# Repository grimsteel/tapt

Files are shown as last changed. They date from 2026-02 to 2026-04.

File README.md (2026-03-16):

# tapt

> just a button

`tapt` is a BLE-powered IoT button. It uses an nRF52810 and can be powered for long periods of time on a single CR2032 battery.

It can be connected to Home Assistant and hooked up to automations from there.

## Usage

> Note: do NOT connect the battery when the board is powered on the debug header.

### Assembly

1. The 5 pin debug header must be soldered on for flashing
2. The battery holder can be soldered onto the back 
3. The WS2812B and the UART are optional. Both of these will cause more battery drain.
4. The PCB can be screwed into the base of the case. The button cap locks into the case.

### Flashing

> Note: An nRF-SDK environment is required. This is a *freestanding project*

1. Customize the device ID and board name if needed in `prj.conf`
1. Build the firmware:
   ```sh
   west build -b tapt -- -DBOARD_ROOT=.
   ```
1. Flash the nRF over SWD, using the SWD header on the board. The pins are labeled on the bottom.

   Firmware is included in the `./firmware` directory.
3. Profit. The button should be autodiscovered in Home Assistant, where it will expose a button entity.

## Purpose

I made this because I wanted a large button for controlling random automations.

I also wanted to learn more about RF PCB design, and the nRF chip was a great place to start.

## Schematic + PCB

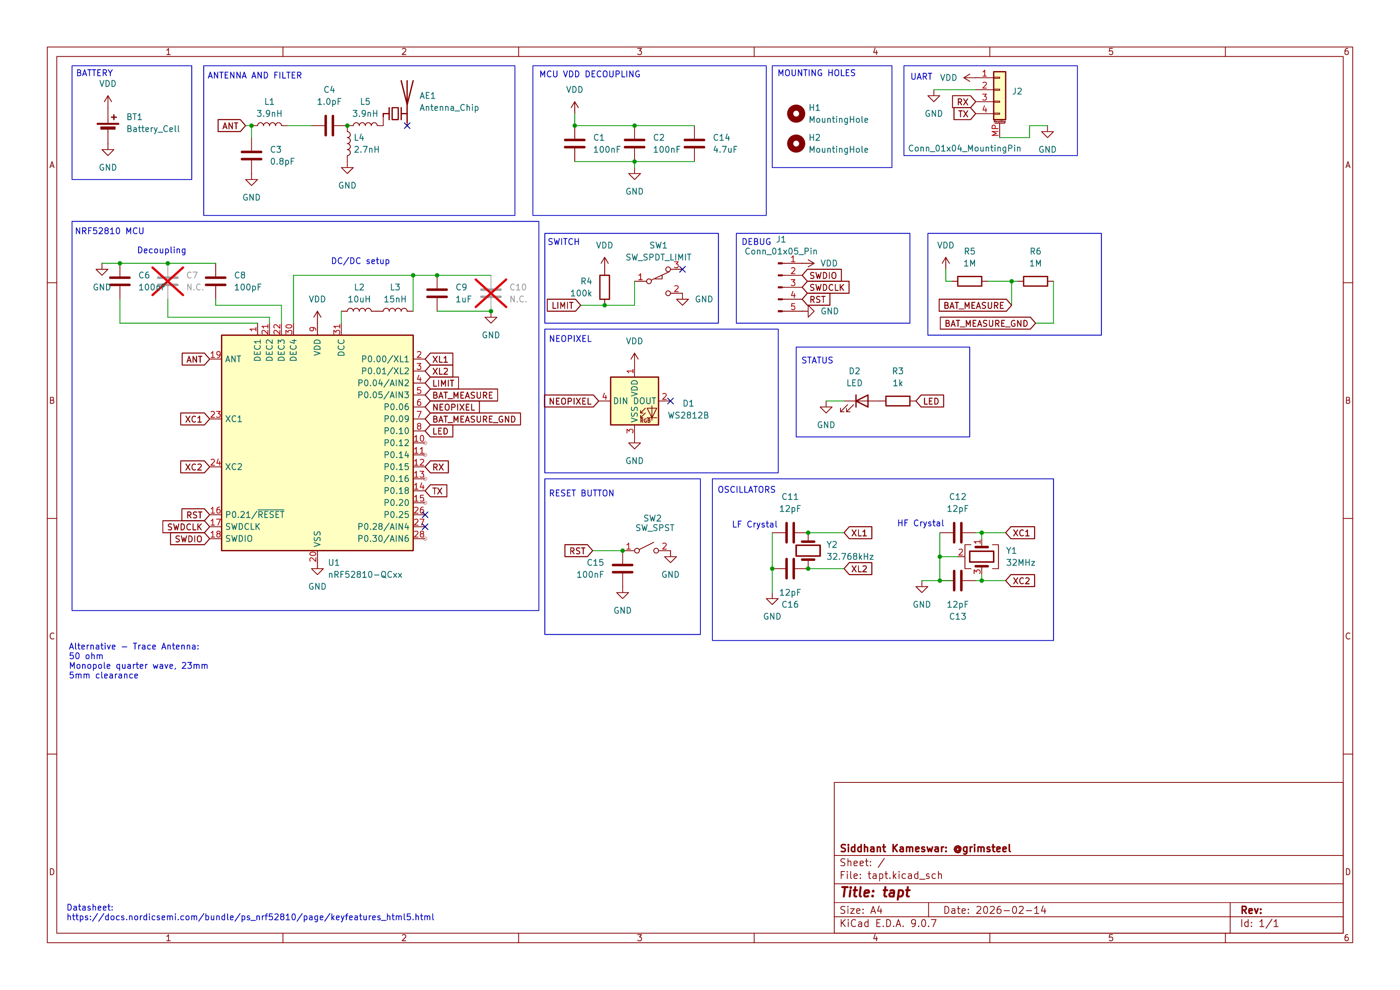
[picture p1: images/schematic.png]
schematic


| F.Cu | In1.Cu | In2.Cu | B.Cu |
|---|---|---|---|
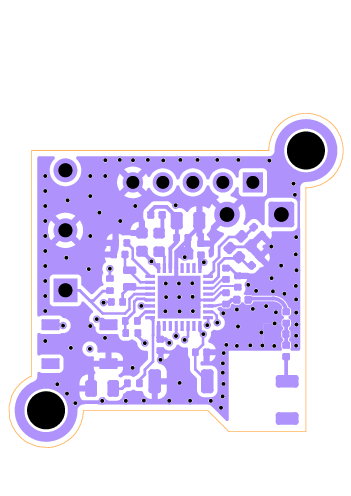
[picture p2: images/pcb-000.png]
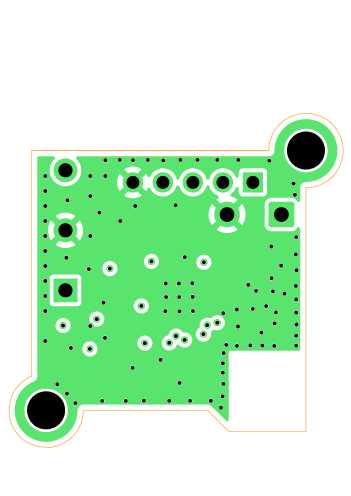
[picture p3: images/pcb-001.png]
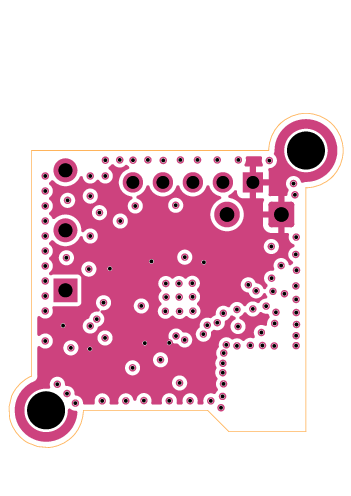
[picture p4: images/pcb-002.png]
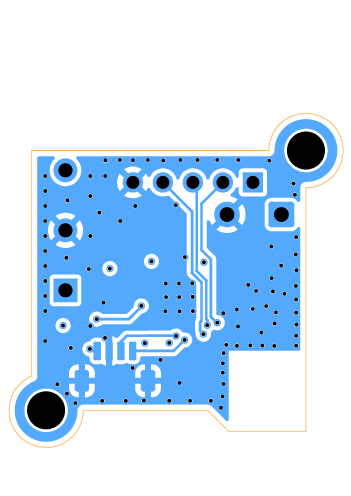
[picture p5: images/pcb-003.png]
|  |  |  |  |
| | | | |

## Case

Apart from the PCB, tapt just has two components: the base and the button. 

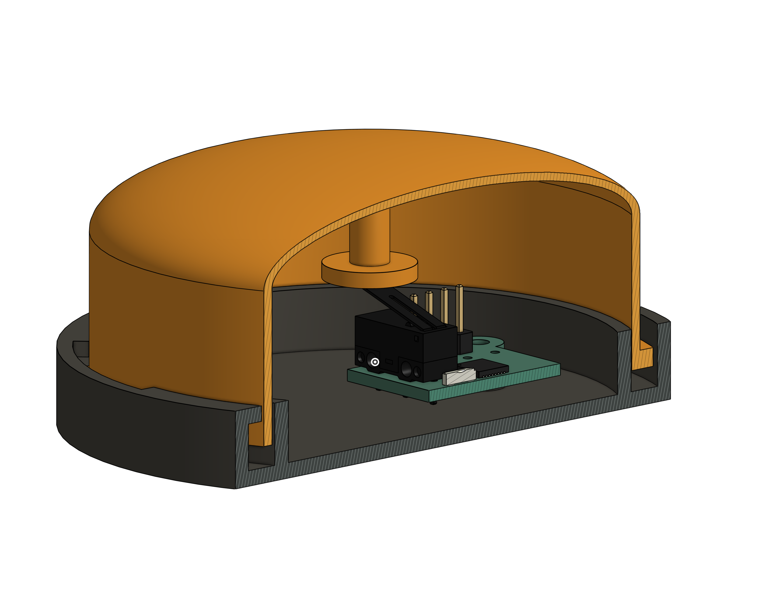
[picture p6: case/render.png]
cad render

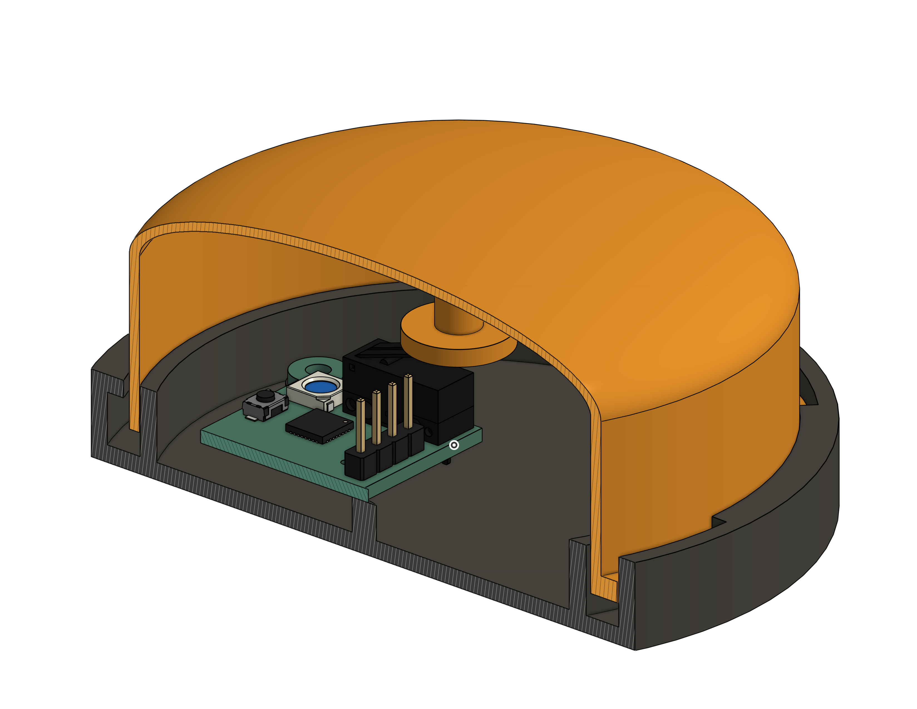
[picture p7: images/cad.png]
antother cad render


The PCB is screwed into the base, and the button sits inside the base. When pressed down, it presses the limit switch.

[Onshape link](https://cad.onshape.com/documents/617a57c855f6b668c2d4cd24/w/013e725e8d7df515c4261645/e/6602b3eddf1a670923f88f78)

## Bill of Materials

[BOM CSV](./bom.csv)

If the price is 0, I have the component already (basically everything except the PCB/PCBA). I added links for reference, though

| Description | Part ID  | Link | Per-unit price | Board Quantity | Total Quantity | Extended? | Total Price | Running Price w/ Tax |
|---|---|---|---|---|---|---|---|---|
| 2.4 GHz Chip Antenna | C89334 | https://jlcpcb.com/partdetail/C89334 | $0.62 | 1 | 5 | TRUE | $6.1630 | $6.69 |
| 100nF Capacitor | C1525 | https://jlcpcb.com/partdetail/C1525 | $0.00 | 4 | 8 | FALSE | $0.0104 | $6.70 |
| 0.8pF Capacitor | C88902 | https://jlcpcb.com/partdetail/C88902 | $0.04 | 1 | 20 | TRUE | $3.7420 | $10.76 |
| 1.0pF Capacitor | C1550 | https://jlcpcb.com/partdetail/C1550 | $0.00 | 1 | 20 | FALSE | $0.0240 | $10.79 |
| 100pF Capacitor | C1546 | https://jlcpcb.com/partdetail/C1546 | $0.00 | 1 | 2 | FALSE | $0.0024 | $10.79 |
| 1uF Capacitor | C28323 | https://jlcpcb.com/partdetail/C28323 | $0.01 | 1 | 2 | FALSE | $0.0254 | $10.82 |
| 12pF Capacitor | C1547 | https://jlcpcb.com/partdetail/C1547 | $0.00 | 4 | 8 | FALSE | $0.0096 | $10.83 |
| 4.7uF Capacitor | C19666 | https://jlcpcb.com/partdetail/C19666 | $0.01 | 1 | 2 | FALSE | $0.0206 | $10.85 |
| Green LED | C2297 | https://jlcpcb.com/partdetail/C2297 | $0.02 | 1 | 2 | FALSE | $0.0314 | $10.88 |
| 3.9nH Inductor | C14033 | https://jlcpcb.com/partdetail/C14033 | $0.00 | 2 | 20 | FALSE | $0.0800 | $10.97 |
| 10uH Inductor | C86083 | https://jlcpcb.com/partdetail/C86083 | $0.05 | 1 | 6 | TRUE | $3.3412 | $14.60 |
| 15nH Inductor | C27143 | https://jlcpcb.com/partdetail/C27143 | $0.05 | 1 | 20 | FALSE | $1.0200 | $15.71 |
| 2.7nH Inductor | C27123 | https://jlcpcb.com/partdetail/C27123 | $0.00 | 1 | 20 | TRUE | $3.1360 | $19.12 |
| 1k Resistor | C11702 | https://jlcpcb.com/partdetail/C11702 | $0.00 | 1 | 2 | FALSE | $0.0014 | $19.12 |
| 100k Resistor | C25741 | https://jlcpcb.com/partdetail/C25741 | $0.00 | 1 | 2 | FALSE | $0.0016 | $19.12 |
| 1M Resistor | C26083 | https://jlcpcb.com/partdetail/C26083 | $0.00 | 2 | 4 | FALSE | $0.0032 | $19.12 |
| SW_SPST Button | C720477  | https://jlcpcb.com/partdetail/C720477 | $0.05 | 1 | 2 | FALSE | $0.1082 | $19.24 |
| nRF52810-QCxx | C519278  | https://jlcpcb.com/partdetail/C519278 | $2.99 | 1 | 2 | TRUE | $9.0228 | $29.04 |
| 32MHz Crystal | C2965582 | https://jlcpcb.com/partdetail/C2965582 | $0.07 | 1 | 6 | TRUE | $3.4606 | $32.80 |
| 32.768kHz Crystal | C97603 | https://jlcpcb.com/partdetail/C97603 | $0.24 | 1 | 5 | TRUE | $4.2365 | $37.40 |
| PCB | | | $1.00 | | 2 | | $2.00 | $39.57 |
| PCBA Fees | | | $11.55 | | 1 | | $11.55 | $52.12 |
| PCB Shipping | | | $3.12 | | 1 | | $3.12 | $55.51 |
| Case | | 3d-printed | $0.00 | | 1 | | $0.00 | $55.51 |
| M3 Heatset | | https://www.aliexpress.us/item/3256802711669116.html | $0.00 | | 2 | | $0.00 | $55.51 |
| M3 Screw x 8mm | | https://www.aliexpress.us/item/2255801013414226.html | $0.00 | | 2 | | $0.00 | $55.51 |
| SPDT Limit Switch | | https://www.aliexpress.us/item/2255800451734482.html | $0.00 | | 1 | | $0.00 | $55.51 |
| 2.54mm Pin Header 1x05 | | https://www.aliexpress.us/item/3256806247917356.html | $0.00 | | 1 | | $0.00 | $55.51 |
| CR2032 Holder | | https://www.aliexpress.us/item/3256810117671035.html | $0.00 | | 1 | | $0.00 | $55.51 |

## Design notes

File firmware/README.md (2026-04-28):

# Connecting to the board

Flashing, logging, and debug is done over SWD.

SWD connections over OpenOCD have two components:
1. The interface: I'm using a Flipper Zero for my SWD-USB adapter, with DAP-link. This means the interface is `cmsis-dap`
2. The target. This is an nRF52.

To connect, run OpenOCD with these specified: (west uses its own openocd, so stop this when flashing)

```sh
openocd -f interface/cmsis-dap.cfg -c "transport select swd" -f target/nrf52.cfg
```

* GDB can be accessed on localhost:3333
* The OpenOCD console can be accessed on telnet localhost:4444

Before any flashing or debugging can be done, run `nrf52_recover` in the OpenOCD console. (**Important!**)

## Building and Flashing

Building is done with `west`.

Because this is a freestanding project, make sure `ZEPHYR_BASE` is set to your nRF install location. I put mine in `~/.local/share/nrf-sdk/v3.2.2/zephyr/`.

Then, start the toolchain environment: `nrfutil sdk-manager toolchain launch --ncs-version v3.2.2  /bin/bash`

1. `west build`
2. `west flash -r openocd` If you're using a different OpenOCD interface, configure this in boards/tapt/board.cmake

## Debugging

Start OpenOCD as mentioned above.

Then, use the specific version of GDB for the chip (make sure you're in the tolchain environment):

```sh
$ arm-zephyr-eabi-gdb build/firmware/zephyr/zephyr.elf
(gdb) target extended-remote localhost:3333
```

## Logs

Logging is done over RTT to avoid the need for a UART peripheral.

First, configure RTT in the OpenOCD console (telnet localhost:4444):

```
> rtt setup 0x20000410 0x30 "SEGGER RTT"
> rtt server start 9001 0
Listening on port 9001 for rtt connections
> rtt start
rtt: Searching for control block 'SEGGER RTT'
rtt: Control block found at 0x20000410
```

The memory address for `rtt setup` should be that one, but if it doesn't find the control block, grep for `_SEGGER_RTT` in `./build/firmware/zephyr/zephyr.map`.

Logs can then be viewed on `telnet localhost:9001`

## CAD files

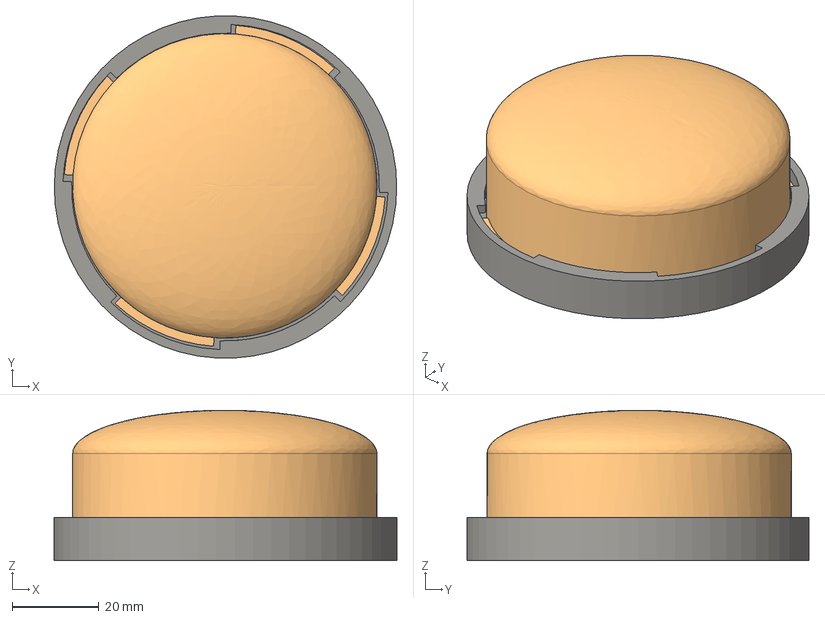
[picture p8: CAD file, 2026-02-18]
case/tapt-assembly.step
79.0 x 78.9 x 34.7 mm
Base
Button
Top001
Plunger001
Bottom001
Pin_NC005
L_1206_3216Metric
LED_WS2812B_PLCC4_5.0x5.0mm_P3.2mm
Pin_C005
Lever_16U001
SW_SPST_TS-1088-xR020
tapt_PCB
Pin_NO005
PinHeader_1x04_P2.54mm_Vertical
QFN-32-1EP_5x5mm_P0.5mm_EP3.7x3.7mm

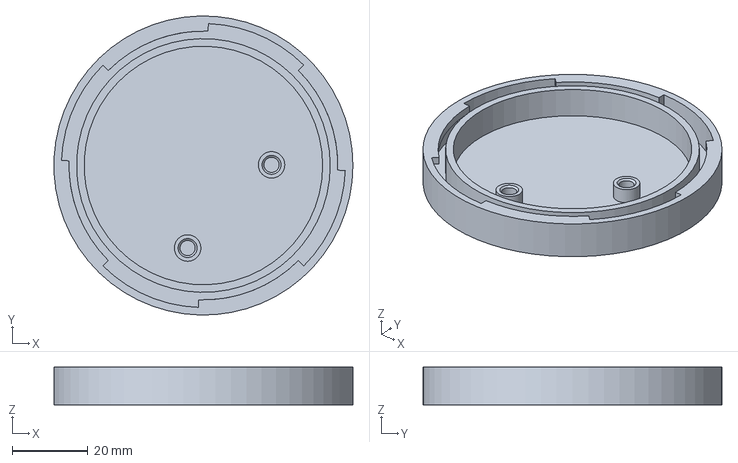
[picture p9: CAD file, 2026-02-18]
case/base.step
78.9 x 79.0 x 10.0 mm

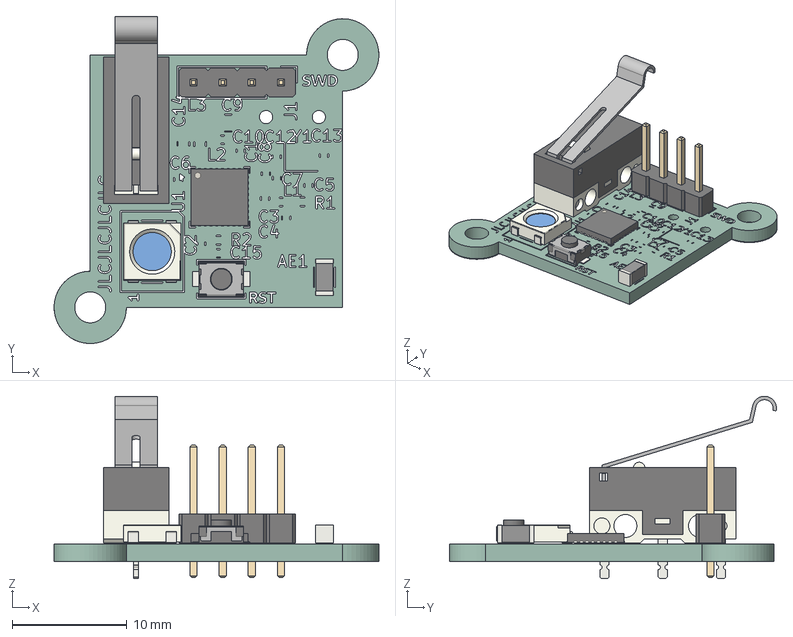
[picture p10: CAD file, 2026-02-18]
pcb/tapt.step
28.3 x 28.5 x 15.9 mm
SW_SPST_TS-1088-xR020
Bottom001
Top001
Plunger001
Lever_16U001
Pin_NO005
Pin_C005
Pin_NC005
PinHeader_1x04_P2.54mm_Vertical
QFN-32-1EP_5x5mm_P0.5mm_EP3.7x3.7mm
L_1206_3216Metric
LED_WS2812B_PLCC4_5.0x5.0mm_P3.2mm
tapt_silkscreen x 2
tapt_PCB

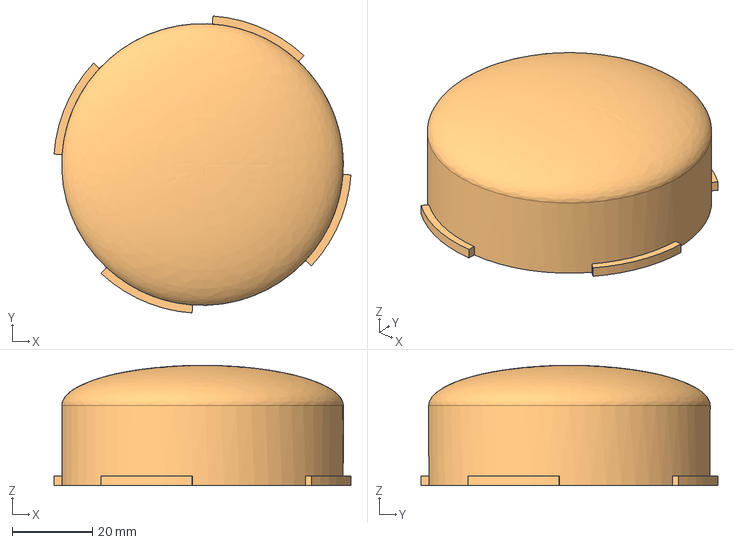
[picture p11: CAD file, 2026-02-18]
case/button.step
74.0 x 74.0 x 30.0 mm

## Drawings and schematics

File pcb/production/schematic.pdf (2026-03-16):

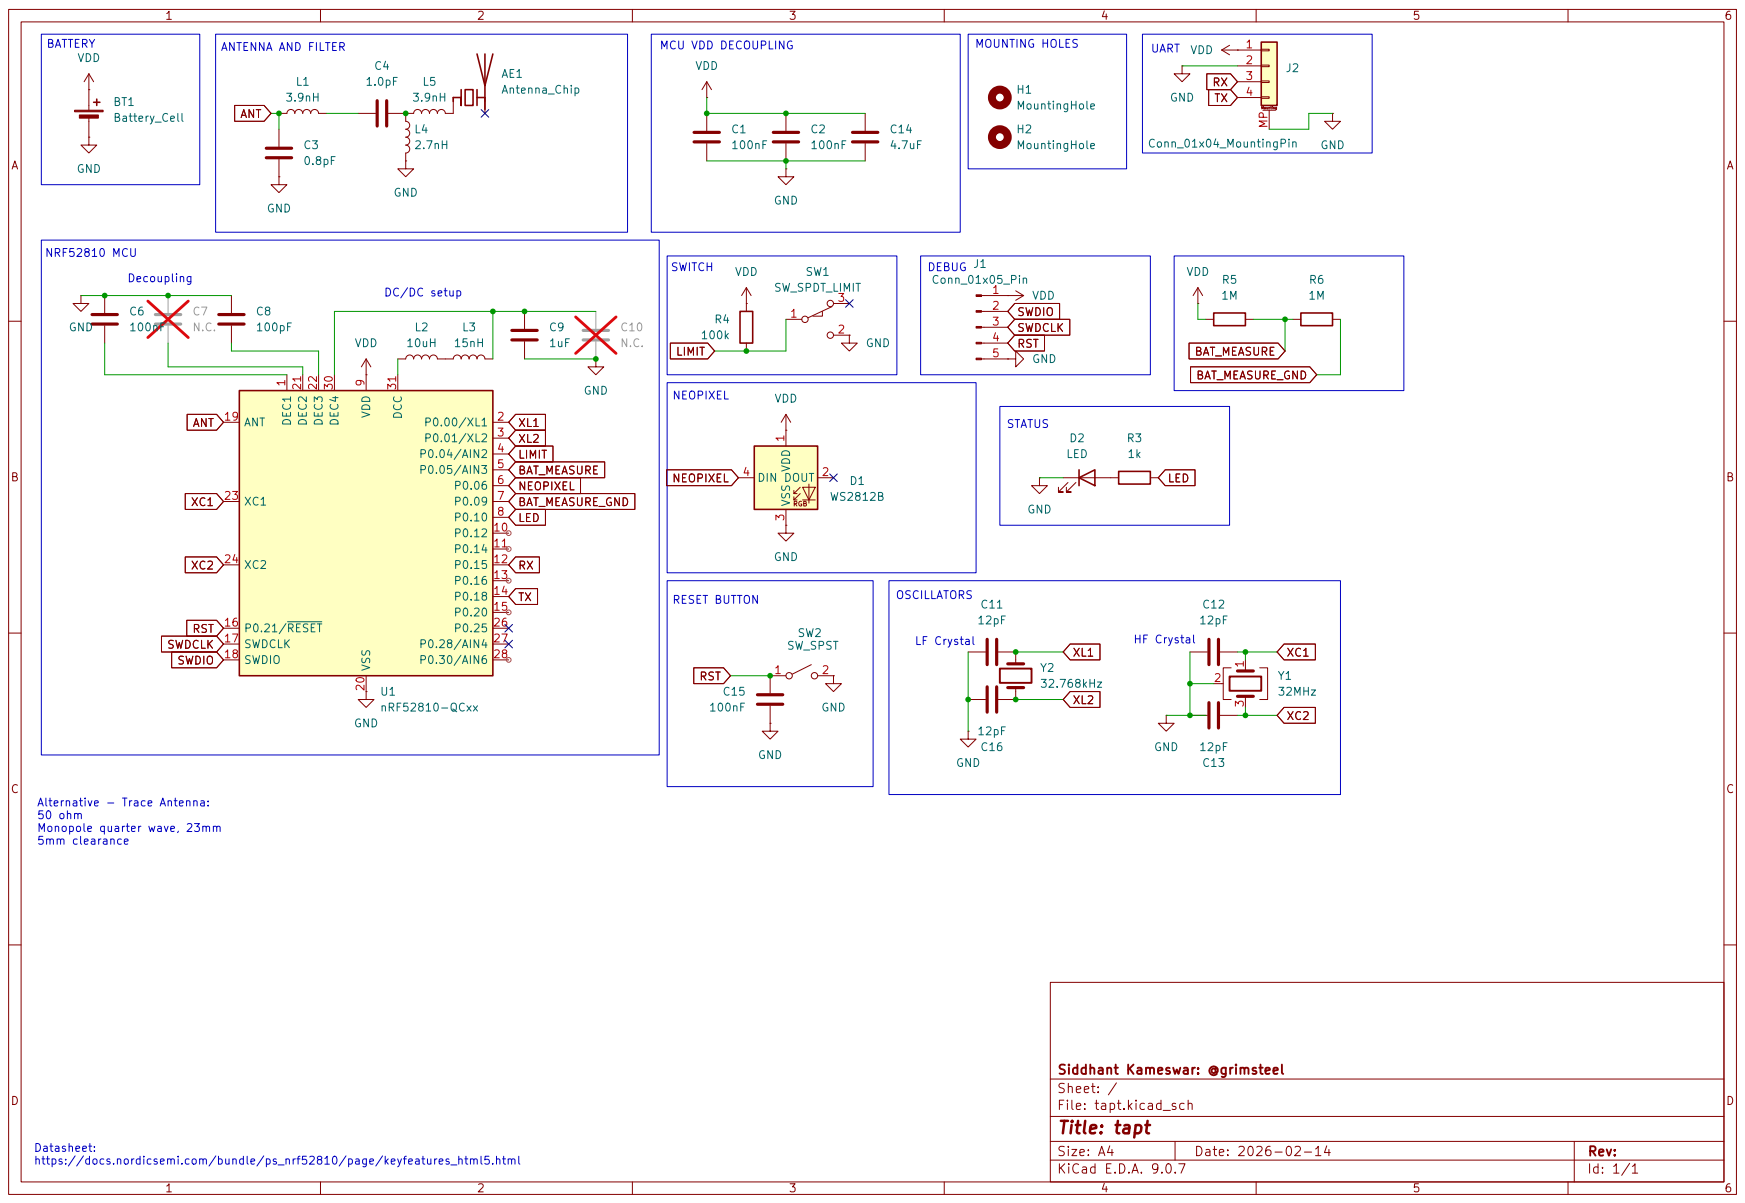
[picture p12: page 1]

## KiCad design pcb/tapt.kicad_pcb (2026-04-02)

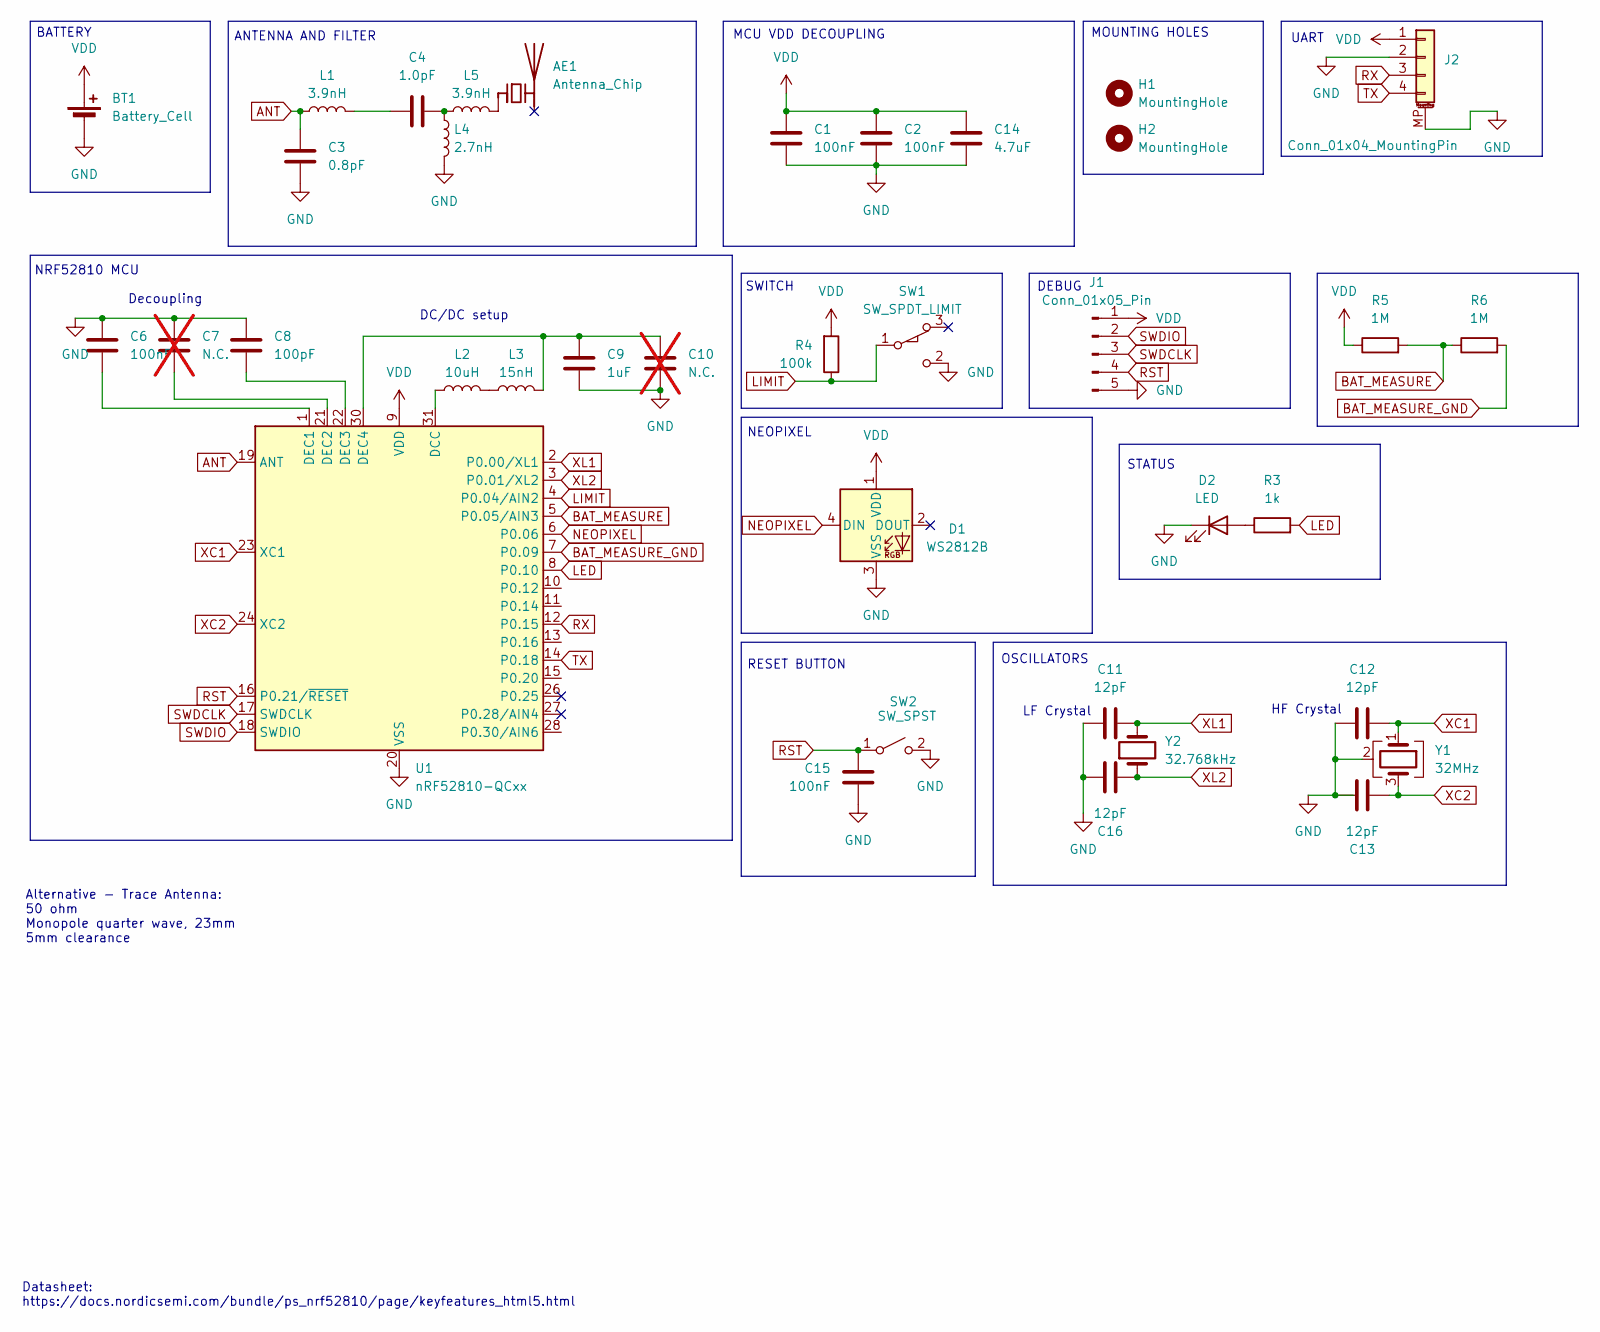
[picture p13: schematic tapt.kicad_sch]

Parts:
AE1: Antenna_Chip; L_1206_3216Metric; LCSC C89334
BT1: Battery_Cell; SolderWire-0.5sqmm_1x02_P4.6mm_D0.9mm_OD2.1mm; LCSC C2979167
C1, C2, C6, C15: 100nF; C_0402_1005Metric; LCSC C1525
C3: 0.8pF; C_0402_1005Metric; LCSC C88902
C4: 1.0pF; C_0402_1005Metric; LCSC C1550
C7, C10: N.C.; C_0402_1005Metric; not fitted
C8: 100pF; C_0402_1005Metric; LCSC C1546
C9: 1uF; C_0805_2012Metric; LCSC C28323
C11, C12, C13, C16: 12pF; C_0402_1005Metric; LCSC C1547
C14: 4.7uF; C_0603_1608Metric; LCSC C19666
D1: WS2812B; LED_WS2812B_PLCC4_5.0x5.0mm_P3.2mm
D2: LED; LED_0805_2012Metric; LCSC C2297
H1, H2: MountingHole; MountingHole_3.2mm_M3
J1: Conn_01x05_Pin; PinHeader_1x05_P2.54mm_Vertical
J2: Conn_01x04_MountingPin; JST_SH_BM04B-SRSS-TB_1x04-1MP_P1.00mm_Vertical
L1, L5: 3.9nH; L_0402_1005Metric; LCSC C14033
L2: 10uH; L_0603_1608Metric; LCSC C86083
L3: 15nH; L_0402_1005Metric; LCSC C27143
L4: 2.7nH; L_0402_1005Metric; LCSC C27123
R3: 1k; R_0402_1005Metric; LCSC C11702
R4: 100k; R_0402_1005Metric; LCSC C25741
R5, R6: 1M; R_0402_1005Metric; LCSC C26083
SW1: SW_SPDT_LIMIT; SW_XKB_DM1-16UP-1
SW2: SW_SPST; SW_SPST_TS-1088-xR020; LCSC C720477
U1: nRF52810-QCxx; QFN-32-1EP_5x5mm_P0.5mm_EP3.6x3.6mm; LCSC C519278
Y1: 32MHz; Crystal_SMD_2016-4Pin_2.0x1.6mm; LCSC C2965582
Y2: 32.768kHz; Crystal_SMD_2012-2Pin_2.0x1.2mm; LCSC C97603

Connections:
ANT: C3.1, L1.1, U1.19 (ANT)
BAT_MEASURE: R5.2, R6.1, U1.5 (P0.05/AIN3)
BAT_MEASURE_GND: R6.2, U1.7 (P0.09)
GND: BT1.2 (-), C1.2, C2.2, C3.2, C6.1, C7.1, C8.1, C9.2, C10.2, C11.1, C12.1, C13.1, C14.2, C15.2, C16.1, D1.3 (VSS), D2.1 (K), J1.5, J2.2, J2.MP (MountPin), L4.2, SW1.2 (B), SW2.2 (B), U1.20 (VSS), U1.29 (VSS), U1.33 (VSS), Y1.2 (G), Y1.4 (G)
LED: R3.2, U1.8 (P0.10)
LIMIT: R4.1, SW1.1 (A), U1.4 (P0.04/AIN2)
NEOPIXEL: D1.4 (DIN), U1.6 (P0.06)
unnamed: AE1.1 (FEED), L5.2
unnamed: C4.1, L1.2
unnamed: C4.2, L4.1, L5.1
unnamed: D2.2 (A), R3.1
unnamed: L2.1, L3.2
unnamed: L2.2, U1.31 (DCC)
unnamed: C6.2, U1.1 (DEC1)
unnamed: C7.2, U1.21 (DEC2)
unnamed: C8.2, U1.22 (DEC3)
unnamed: C9.1, C10.1, L3.1, U1.30 (DEC4)
RST: C15.1, J1.4, SW2.1 (A), U1.16 (P0.21/~RESET)
RX: J2.3, U1.12 (P0.15)
SWDCLK: J1.3, U1.17 (SWDCLK)
SWDIO: J1.2, U1.18 (SWDIO)
TX: J2.4, U1.14 (P0.18)
VDD: BT1.1 (+), C1.1, C2.1, C14.1, D1.1 (VDD), J1.1, J2.1, R4.2, R5.1, U1.9 (VDD), U1.25 (VDD), U1.32 (VDD)
XC1: C12.2, U1.23 (XC1), Y1.1
XC2: C13.2, U1.24 (XC2), Y1.3
XL1: C11.2, U1.2 (P0.00/XL1), Y2.2
XL2: C16.2, U1.3 (P0.01/XL2), Y2.1

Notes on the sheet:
DC/DC setup
RESET BUTTON
ANTENNA AND FILTER
Alternative - Trace Antenna: 50 ohm Monopole quarter wave, 23mm 5mm clearance
UART
HF Crystal
MCU VDD DECOUPLING
Decoupling
SWITCH
OSCILLATORS
MOUNTING HOLES
LF Crystal
NEOPIXEL
STATUS
NRF52810 MCU
BATTERY
DEBUG
Datasheet: https://docs.nordicsemi.com/bundle/ps_nrf52810/page/keyfeatures_html5.html

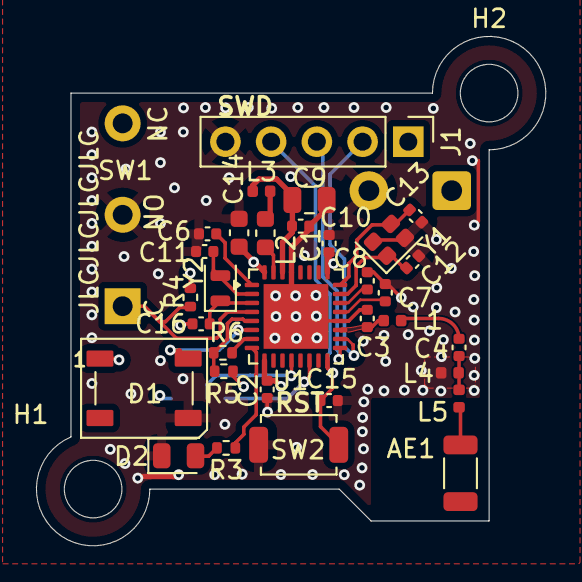
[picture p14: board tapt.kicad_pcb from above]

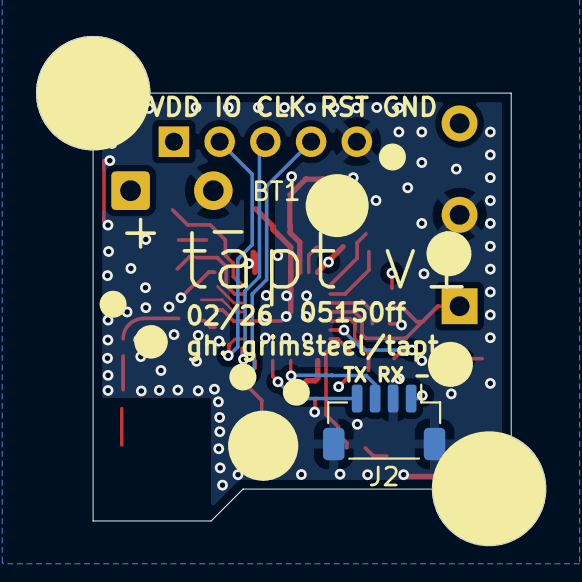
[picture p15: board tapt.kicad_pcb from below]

Board: 4 copper layers, 28.3 x 28.3 mm, 37 parts (2 on the bottom side), 27 nets.

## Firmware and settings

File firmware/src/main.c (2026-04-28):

#include <zephyr/kernel.h>
#include <zephyr/logging/log.h>
#include <zephyr/drivers/gpio.h>
#include <zephyr/drivers/hwinfo.h>
#include <zephyr/sys/poweroff.h>
#include <zephyr/sys/util.h>
#include <zephyr/device.h>
#include "battery.h"
#include "bluetooth.h"

LOG_MODULE_REGISTER(main, CONFIG_APP_LOG_LEVEL);

void power_off(void) {
  hwinfo_clear_reset_cause();
  sys_poweroff();
}

int main(void) {
  // test SWD logging (non trivial?)
  LOG_DBG("Hello, world!");

  const struct gpio_dt_spec status_led = GPIO_DT_SPEC_GET(DT_ALIAS(status_led), gpios);
  if (!gpio_is_ready_dt(&status_led)) {
    LOG_ERR("Status LED is not ready");
    return -ENODEV;
  }

  int error;

  // apply cfg
  if ((error = gpio_pin_configure_dt(&status_led, GPIO_OUTPUT_ACTIVE))) {
    LOG_ERR("Status LED config error: %d", error);
    return error;
  }

  // flash for 0.2s
  gpio_pin_set_dt(&status_led, 1);
  k_sleep(K_MSEC(200));
  gpio_pin_set_dt(&status_led, 0);

  // configure button for wakeup
  const struct gpio_dt_spec limit_switch = GPIO_DT_SPEC_GET(DT_ALIAS(limit_switch), gpios);
  if (!gpio_is_ready_dt(&limit_switch)) {
    LOG_ERR("Limit switch is not ready");
    return -ENODEV;
  }

  // apply cfg
  if ((error = gpio_pin_configure_dt(&limit_switch, GPIO_INPUT))) {
    LOG_ERR("Limit switch config error: %d", error);
    return error;
  }

  // enable interrupt
  if ((error = gpio_pin_interrupt_configure_dt(&limit_switch, GPIO_INT_LEVEL_ACTIVE))) {
    LOG_ERR("Limit switch interrupt enable error: %d", error);
    return error;
  }

  battery_sensor_t battery;
  if ((error = battery_sensor_init(&battery))) return error;
  int32_t battery_level;
  if ((error = battery_sensor_read(&battery, &battery_level))) return error;

  // determine if button pressed (power on due to gpio interrupt)
  uint32_t reset_cause;
  hwinfo_get_reset_cause(&reset_cause);
  bool button_pressed = (reset_cause & RESET_LOW_POWER_WAKE) != 0;

  // send bluetooth advertisment, with button pressed if applicable
  if ((error = bluetooth_init())) return error;
  if ((error = bluetooth_advertise(battery_level, button_pressed))) return error;

  // wait 1s then power off
  k_sleep(K_MSEC(500));
  
  if ((error = bluetooth_advertise_stop())) return error;
  power_off();
  
  return 0;
}

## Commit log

2026-01-06 initial schematic
    [tapt.kicad_pcb, tapt.kicad_sch]
2026-02-14 schematic: antenna, reset button
    [tapt.kicad_sch]
2026-02-14 pcb: layout and routing
    [tapt.kicad_pcb]
2026-02-14 major rf improvements, battery connector, component relayout
    [tapt.kicad_pcb, tapt.kicad_sch]
2026-02-14 add mounting holes on dogboned corners
    [tapt.kicad_pcb, tapt.kicad_sch]
2026-02-15 pcb: silkscreen
    [tapt.kicad_pcb]
2026-02-18 case and readme
    [base.step, button.step, tapt-assembly.step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]
2026-02-27 schematic: status led, uart
    [tapt.kicad_pcb, tapt.kicad_sch]
2026-02-28 pcb: uart, status led
    [tapt.kicad_pcb, tapt.kicad_sch]
2026-03-01 pcb: 4 layer redesign, more antenna tuning, low freq crystal
    [tapt.kicad_pcb, tapt.kicad_sch]
2026-03-07 pcb: clock routing improvements
    [tapt.kicad_pcb]
2026-03-12 firmware: board config, build config, prj.conf
2026-03-12 pcb: battery voltagef divider, hf clock routing
    [tapt.kicad_pcb, tapt.kicad_sch]
2026-03-15 firmware: finish initial firmware, ble, battery level, device tree
2026-03-15 pcb: voltage divider, antenna t-network
    [tapt.kicad_pcb, tapt.kicad_sch]
2026-03-15 pcb: minor rf routing improvements
    [tapt.kicad_pcb]
2026-03-16 chore: production files, bom, readme updates
    [bom.ods, tapt.kicad_pcb]
2026-03-16 chore: unignore bom file
    [bom.csv]
2026-04-02 pcb: impedance matching fixes
    [tapt.kicad_pcb]
2026-04-02 pcb: update production files
    [tapt.kicad_pcb]
2026-04-28 firmware: fix bugs, add detailed build/flash/debug instructions
    [main.c]
2026-04-28 chore(pcb): kicad 10 project file updates
